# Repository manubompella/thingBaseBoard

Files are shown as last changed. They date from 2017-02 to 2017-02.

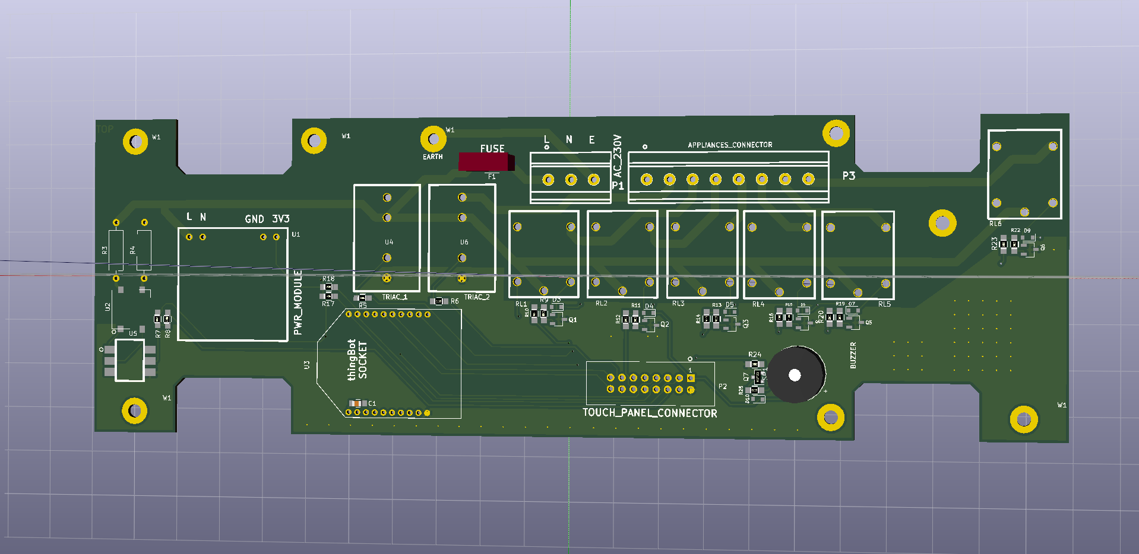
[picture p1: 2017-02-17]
v1.0/images/thingBaseBoard_v1P0_Front.png

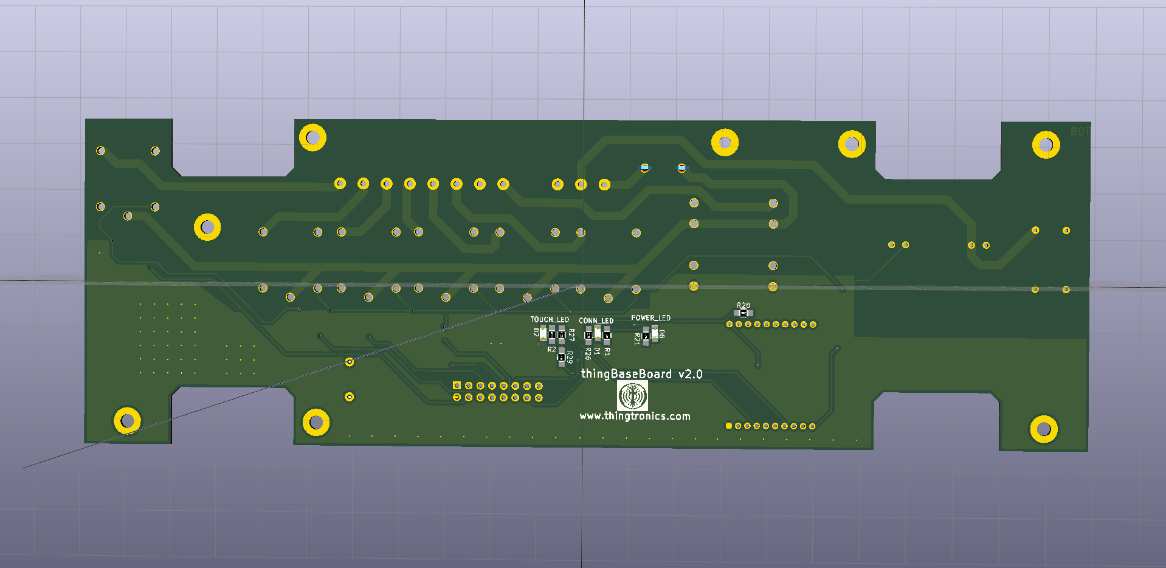
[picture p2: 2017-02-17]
v1.0/images/thingBaseBoard_v1P0_Back_Real.png

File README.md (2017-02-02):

# thingBaseBoard

The thingBaseBoard hosts the power supply unit, relays, triacs and the connectors for connecting to the thingTouch and the thingBots in a regular 8 module electrical box

## Platform Features

  * [XBee Compatible Socket](https://www.sparkfun.com/datasheets/Wireless/Zigbee/XBee-Dimensional.pdf)
  * Power ON Led
  * 230V Vin
  
## Maintainers

The thingBaseBoard is maintained by thingTronics Innovations.

Main contributor:
 * Manohar Bompella @<manohar.bompella@thingtronics.com>
 * Lovelesh Patel @<lovelesh.patel@thingtronics.com>

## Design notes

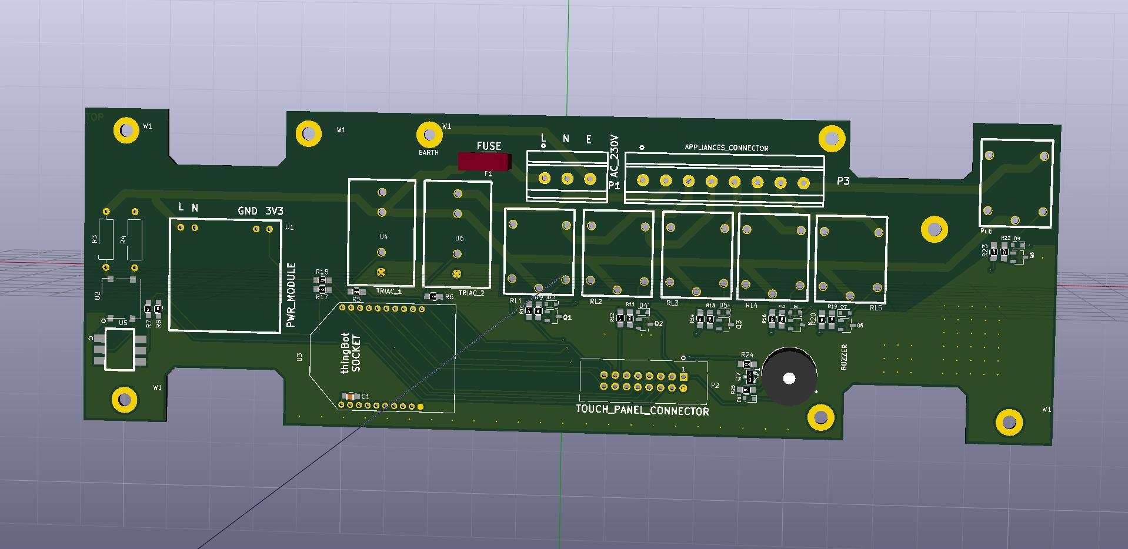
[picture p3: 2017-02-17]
v1.0/images/thingBaseBoard_v1P0_Front_Real_1.jpg

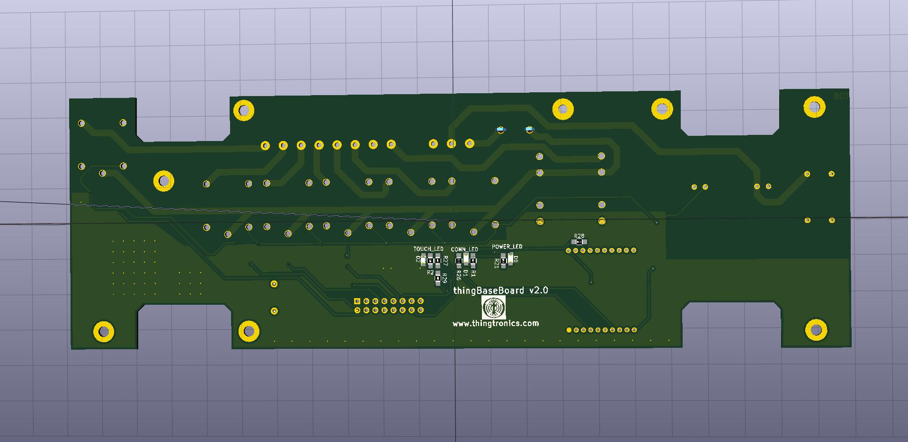
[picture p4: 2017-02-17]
v1.0/images/thingBaseBoard_v1P0_Back_Real_1.jpg

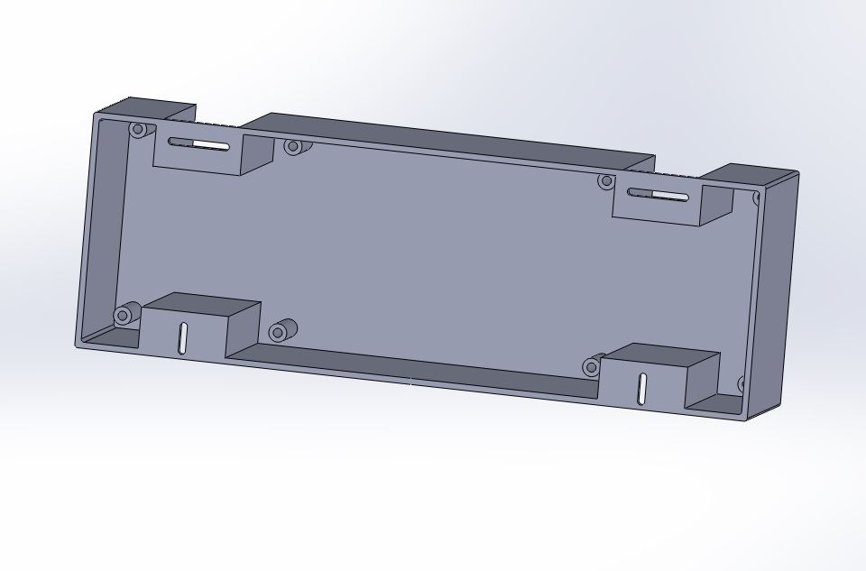
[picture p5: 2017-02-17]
Reference/Case_3D_view.jpeg

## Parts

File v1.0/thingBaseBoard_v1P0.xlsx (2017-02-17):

Reference | Quantity | Value | Footprint | DESC | MFG_NAME | MPN | PCB Package | 1 | 100 | 500 | 1000 |  | 10 PCB | 100 PCB | 1000 PCB | Purchased cost for 100
C1 | 1 | 10uF | Capacitors_SMD:C_0805_HandSoldering | Multilayer Ceramic Capacitors MLCC - SMD/SMT 10 uF 16V 10% | Yageo | AC0805KRX7R9BB103 | 805 | 3.5 | 2.1 | 2.1 | 2.1 |  | 3.5 | 2.1 | 2.1
D1 | 1 | CONN_LED | LEDs:LED_0805 | Yellow led for Data connection ndication | Kingbright | AP2012SRCPRV | 805 | 9.1 | 4.76 | 4.76 | 4.55 |  | 9.1 | 4.76 | 4.55
D2 | 1 | TOUCH_LED | LEDs:LED_0805 | Red led for Touch indication indication | Kingbright | AP2012SRCPRV | 805 | 9.1 | 4.76 | 4.76 | 4.55 |  | 9.1 | 4.76 | 4.55
D10 D3 D4 D5 D6 D7 D9 | 7 | 1N4007 | Diodes_SMD:D_0805 | 1N4007 (1A at 1000V), SMD Package: SMA (DO-214AC) SOD126 | SUNROM | 4455 | 805 | 1 | 1 | 1 | 1 |  | 7 | 7 | 7
D8 | 1 | POWER_LED | LEDs:LED_0805 | green led for Power indication | Kingbright | AP2012SRCPRV | 805 | 9.1 | 4.76 | 4.76 | 4.55 |  | 9.1 | 4.76 | 4.55
F1 | 1 | FUSE | Fuse:8mm_Pitch | 5A 250V Slow Blow Fuse 3.6x10mm with Leads | SUNROM | 5167 | TH | 5.5 | 5.23 | 4.95 | 4.95 |  | 5.5 | 5.23 | 4.95
P1 | 1 | AC_230V | Connectors:gmkds_3-3-5,8 | 3 Pin Screw Connector | Phoenix Contact (http://www.mouser.in/Phoenix-Contact/) | 1729128 | TH | 69.3 | 62.02 | 53.48 | 49.35 |  | 69.3 | 62.02 | 49.35
P2 | 1 | TOUCH_PANEL_CONNECTOR | Connectors:IDC_Header_Straight_16pins | 16 pinStraight through hole box connector | 3M Electronic Solutions Division | N2516-6002RB | TH | 135.8 | 98 | 83.3 | 77.7 |  | 135.8 | 98 | 77.7
P3 | 1 | APPLIANCES_CONNECTOR | Connectors:gmkds_3-8-5,8 | 8 Pin Screw Connector | Phoenix Contact (http://www.mouser.in/Phoenix-Contact/) | 1729128 | TH | 69.3 | 62.02 | 53.48 | 49.35 |  | 69.3 | 62.02 | 49.35
Q1 Q2 Q3 Q4 Q5 Q6 | 6 | 2N3904-MMBT | TO_SOT_Packages_SMD:TSOT-23 | Bipolar Transistors - BJT SOT-23 NPN GEN PUR | Fairchild Semiconductor | MMBT3904 | SMD | 9.8 | 3.36 | 3.36 | 2.24 |  | 58.8 | 20.16 | 13.44
Q7 | 1 | 2N7002 | TO_SOT_Packages_SMD:SOT-23 | MOSFET 60V 115mA N-Channel | ON Semiconductor (http://www.mouser.in/onsemiconductor/) | 2N7002LT1G | SMD | 9.1 | 3.01 | 3.01 | 2.03 |  | 9.1 | 3.01 | 2.03
R17 R18 | 2 | 3K3 | Resistors_SMD:R_0805_HandSoldering | Current Sense Resistors - SMD 0805 0.002ohm 1% AEC-Q200 | ROHM Semiconductor | PMR10EZPFV2L00 | 805 | 7.7 | 2.8 | 2.8 | 2.59 |  | 15.4 | 5.6 | 5.18
R21 | 1 | 470E | Resistors_SMD:R_0805_HandSoldering | Current Sense Resistors - SMD 0805 0.002ohm 1% AEC-Q200 | ROHM Semiconductor | PMR10EZPFV2L00 | 805 | 7.7 | 2.8 | 2.8 | 2.59 |  | 7.7 | 2.8 | 2.59
R24 | 1 | 22K | Resistors_SMD:R_0805_HandSoldering | Current Sense Resistors - SMD 0805 0.002ohm 1% AEC-Q200 | ROHM Semiconductor | PMR10EZPFV2L00 | 805 | 7.7 | 2.8 | 2.8 | 2.59 |  | 7.7 | 2.8 | 2.59
R25 | 1 | 150K | Resistors_SMD:R_0805_HandSoldering | Current Sense Resistors - SMD 0805 0.002ohm 1% AEC-Q200 | ROHM Semiconductor | PMR10EZPFV2L00 | 805 | 7.7 | 2.8 | 2.8 | 2.59 |  | 7.7 | 2.8 | 2.59
R3 R4 | 2 | 150K | Resistors_ThroughHole:R_Axial_DIN0309_L9.0mm_D3.2mm_P12.70mm_Horizontal | hick Film Resistors - Through Hole 150K ohm 5% | KOA Speer | RCR50CT52R473J | TH | 30.8 | 7.42 | 7.42 | 7.42 |  | 61.6 | 14.84 | 14.84
R10 R12 R14 R16 R20 R23 R28 R29 R5 R6 R8 | 11 | 0E | Resistors_SMD:R_0805_HandSoldering | Current Sense Resistors - SMD 0805 0.002ohm 1% AEC-Q200 | ROHM Semiconductor | PMR10EZPFV2L00 | 805 | 7.7 | 2.8 | 2.8 | 2.59 |  | 84.7 | 30.8 | 28.49
R7 | 1 | 10K | Resistors_SMD:R_0805_HandSoldering | Current Sense Resistors - SMD 0805 0.002ohm 1% AEC-Q200 | ROHM Semiconductor | PMR10EZPFV2L00 | 805 | 7.7 | 2.8 | 2.8 | 2.59 |  | 7.7 | 2.8 | 2.59
R1 R11 R13 R15 R19 R2 R22 R9 | 8 | 100E | Resistors_SMD:R_0805_HandSoldering | Current Sense Resistors - SMD 0805 0.002ohm 1% AEC-Q200 | ROHM Semiconductor | PMR10EZPFV2L00 | 805 | 7.7 | 2.8 | 2.8 | 2.59 |  | 61.6 | 22.4 | 20.72
RL1 RL2 RL3 RL4 RL5 RL6 | 6 | G5Q-1 | relays:Songle_SRD-03VDC-SL-C | Songle 3V Relay SRD-03VDC-SL-C | Songle | SRD-03VDC-SL-C | TH | 50 | 40 | 40 | 30 |  | 300 | 240 | 180
SP1 | 1 | BUZZER | Buzzers_Beepers:Buzzer_12x9.5RM7.6 | Piezo Passive Buzzer 14mm | SUNROM | 4801 | TH | 25 | 22.5 | 22.5 | 22.5 |  | 25 | 22.5 | 22.5
U1 | 1 | HenLv-AC220S3_3DCS-3W | HenLv_power_modules:AC220S3.3DCS-3W HenLv | AC220S3.3DCS-3W Power Module HenLv | HenLv | AC220S3.3DCS-3W | TH | 300 | 290 | 280 | 250 |  | 300 | 290 | 250
U2 | 1 | DF08S1_BRIDGE_REC-IC | diodes:DF08S1_DIODE_BRIDGE | Bridge Rectifier | Fairchild Semiconductor (http://www.mouser.in/Fairchild-Semiconductor/) | DF08S | SMD | 30.8 | 15.89 | 15.89 | 12.25 |  | 30.8 | 15.89 | 12.25
U3 | 1 | XBEE_MODULE | Xbee:XBee_Socket_without_Jtag | 1x20 Female straight Header 2.0mm TH | Harwin | M22-2510205 | TH | 13.3 | 6.37 | 6.37 | 5.6 |  | 13.3 | 6.37 | 5.6
U5 | 1 | 4N35_OPTO | optocoupler:4N35_OPTOCOUPLER | Transistor Output Optocouplers Phototransistor Out Single CTR >100% | Vishay Semiconductors (http://www.mouser.in/vishaysemiconductors/) | 4N35-X009T | SMD | 51 | 25.27 | 19.04 | 17.22 |  | 51 | 25.27 | 17.22
U4 U6 | 2 | TRIAC_BOARD | Triac_boards:Triac_board_v1.0 | thingTronics Triac Board v1.0 | thingTronics |  | TH | 100 | 97 | 97 | 91 |  | 200 | 194 | 182
W1 | 1 | EARTH | Wire_Pads:SolderWirePad_single_1-2mmDrill | DNM |  |  |  |  |  |  |  |  | 0 | 0 | 0
R26 R27 | 2 | 0E |  | DNM |  |  |  |  |  |  |  |  | 0 | 0 | 0
 |  |  |  |  |  |  |  |  |  |  |  | TOTAL | 1359.8 | 958.69 | 786.73

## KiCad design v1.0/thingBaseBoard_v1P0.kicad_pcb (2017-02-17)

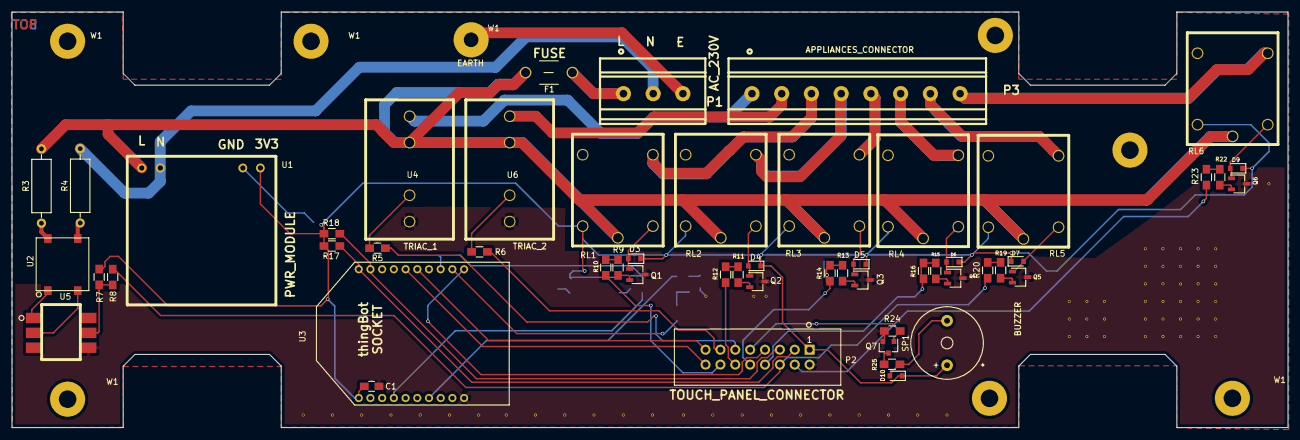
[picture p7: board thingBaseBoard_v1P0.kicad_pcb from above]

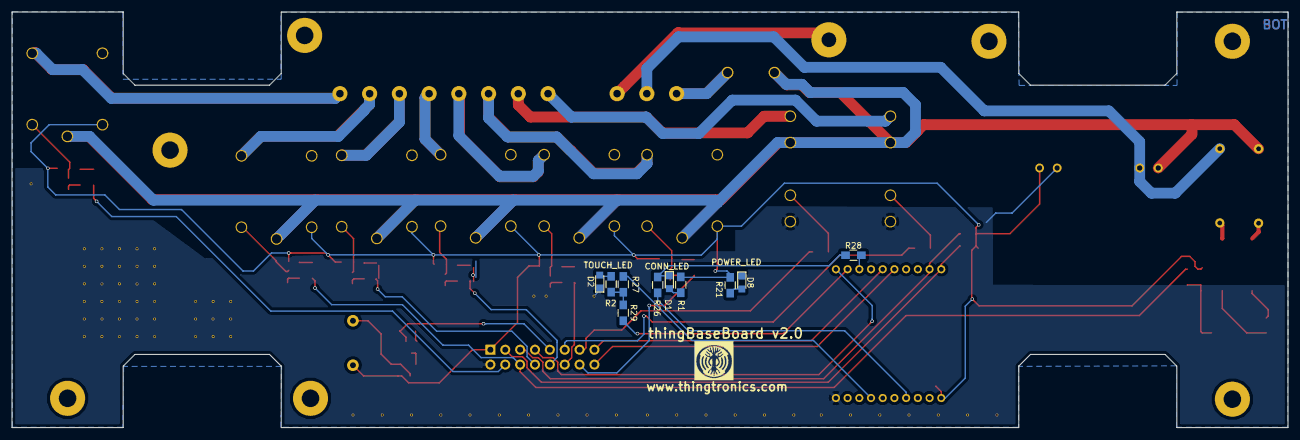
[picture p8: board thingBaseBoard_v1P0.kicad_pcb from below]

Board: 2 copper layers, 218.0 x 71.0 mm, 72 parts (10 on the bottom side), 64 nets.

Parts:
C1: 10uF; C_0805_HandSoldering
D1: CONN_LED; LED_0805
D2: TOUCH_LED; LED_0805
D3, D4, D5, D6, D7, D9, D10: 1N4007; D_0805
D8: POWER_LED; LED_0805
F1: FUSE; 8mm_Pitch
P1: AC_230V; gmkds_3-3-5,08
P2: TOUCH_PANEL_CONNECTOR; IDC_Header_Straight_16pins
P3: APPLIANCES_CONNECTOR; gmkds_3-8-5,08
Q1, Q2, Q3, Q4, Q5, Q6: 2N3904-MMBT; TSOT-23
Q7: 2N7002; SOT-23
R1, R2, R9, R11, R13, R15, R19, R22: 100E; R_0805_HandSoldering
R3, R4: 150K; R_Axial_DIN0309_L9.0mm_D3.2mm_P12.70mm_Horizontal
R5, R6, R8, R10, R12, R14, R16, R20, R23, R26, R27, R28, R29: 0E; R_0805_HandSoldering
R7: 10K; R_0805_HandSoldering
R17, R18: 3K3; R_0805_HandSoldering
R21: 470E; R_0805_HandSoldering
R24: 22K; R_0805_HandSoldering
R25: 150K; R_0805_HandSoldering
RL1, RL2, RL3, RL4, RL5, RL6: G5Q-1; Songle_SRS-03VDC-SL
SP1: BUZZER; Buzzer_12x9.5RM7.6
U1: HenLv-AC220S3_3DCS-3W; AC220S3.3DCS-3W HenLv
U2: DF08S1_BRIDGE_REC-IC; DF08S1_DIODE_BRIDGE
U3: XBEE_MODULE; XBee_Socket_without_Jtag
U4, U6: TRIAC_BOARD; Triac_board_v1.0
U5: 4N35_OPTO; 4N35_OPTOCOUPLER
W1, W1#2, W1#3, W1#4, W1#5, W1#6, W1#7, W1#8: EARTH; SolderWirePad_single_2-5mmDrill

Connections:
+3V3: C1.1, D3.1, D4.1, D5.1, D6.1, D7.1, D9.1, D10.1, P2.1, R1.1, R7.1, R17.1, R18.1, R21.1, RL1.2, RL2.2, RL3.2, RL4.2, RL5.2, RL6.2, SP1.1, U1.4, U3.1
BUZZER: P2.9, Q7.1, R24.2
CONNECT_LED: D1.1, R26.2, R28.1
GND: C1.2, D2.1, D8.1, P2.2, Q1.3, Q2.3, Q3.3, Q4.3, Q5.3, Q6.3, Q7.2, R24.1, U1.3, U3.10, U4.1, U5.4, U6.1
I2C_SCL: P2.5, R18.2, U3.19
I2C_SDA: P2.3, R17.2, U3.20
L: F1.2, R3.2, RL1.3, RL2.3, RL3.3, RL4.3, RL5.3, RL6.3, U1.1, U4.3, U6.3
LS_INTR: P2.15, U3.15
N: P1.2, R4.2, U1.2
unnamed: D1.2, R1.2
unnamed: D2.2, R2.2
unnamed: D3.2, Q1.1, RL1.1
unnamed: D4.2, Q2.1, RL2.1
unnamed: D5.2, Q3.1, RL3.1
unnamed: D6.2, Q4.1, RL4.1
unnamed: D7.2, Q5.1, RL5.1
unnamed: D8.2, R21.2
unnamed: D9.2, Q6.1, RL6.1
unnamed: D10.2, R25.2, SP1.2
unnamed: F1.1, P1.1
unnamed: P1.3, W1#8.1
unnamed: P3.1, U4.4
unnamed: P3.2, U6.4
unnamed: P3.3, RL1.5
unnamed: P3.4, RL2.5
unnamed: P3.5, RL3.5
unnamed: P3.6, RL4.5
unnamed: P3.7, RL5.5
unnamed: P3.8, RL6.5
unnamed: Q1.2, R9.1
unnamed: Q2.2, R11.1
unnamed: Q3.2, R13.1
unnamed: Q4.2, R15.1
unnamed: Q5.2, R19.1
unnamed: Q6.2, R22.1
unnamed: Q7.3, R25.1
unnamed: R3.1, U2.4
unnamed: R4.1, U2.3
unnamed: R5.1, U4.2
unnamed: R6.1, U6.2
unnamed: R7.2, R8.2, U5.5
unnamed: R9.2, R10.1
unnamed: R11.2, R12.1
unnamed: R13.2, R14.1
unnamed: R15.2, R16.1
unnamed: R19.2, R20.1
unnamed: R22.2, R23.1
unnamed: R26.1, U3.4
unnamed: R27.1, U3.7
unnamed: R28.2, U3.13
unnamed: R29.2, U3.12
unnamed: U2.1, U5.1
unnamed: U2.2, U5.2
RELAY_1: P2.14, R10.2
RELAY_2: P2.12, R12.2
RELAY_3: P2.10, R14.2
RELAY_4: P2.8, R16.2
RELAY_5: P2.6, R8.1, R20.2
RELAY_6: P2.4, R23.2
TOUCH_INTR: P2.7, U3.11
TOUCH_LED: R2.1, R27.2, R29.1
TRIAC_1: P2.11, R5.2
TRIAC_2: P2.13, R6.2
TS_INTR: P2.16, U3.16

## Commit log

2017-02-02 Added directory structure and reference schematic
2017-02-02 Updated README and added 3.3V power supply reference
2017-02-03 Schematic Added
    Schematic Added
    Reference Files Added
    [thingBaseBoard_v1P0.sch]
2017-02-13 All footprints are placed in Layout
    All footprints are placed in Layout
    - silk Screen Added for all
    - size of the Pcb decreased by 2mm
    [thingBaseBoard_v1P0.kicad_pcb, thingBaseBoard_v1P0.sch]
2017-02-15 Routing done
    routing Completed,
    Power Module footprint Changed,
    2mm size of the PCB reduced.
    [thingBaseBoard_v1P0.kicad_pcb, thingBaseBoard_v1P0.sch]
2017-02-17 Bom Create, Holes made in Layout, Schematic Changed
    - Bom generated
    - in schematic Mosfet Q7 Changed
    - in layout mounting holes made
    [thingBaseBoard_v1P0.kicad_pcb, thingBaseBoard_v1P0.sch, thingBaseBoard_v1P0.xlsx]
